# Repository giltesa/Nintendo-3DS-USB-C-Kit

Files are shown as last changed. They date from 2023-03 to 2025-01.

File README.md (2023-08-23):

# Nintendo 3DS USB-C Kit

The **Nintendo 3DS: USB-C Kit** is a board that allows to replace the original charging connector for a modern and standard **USB-C**.

**If your original connector is too old or damaged** and you need a new one, or **if you would like to charge your Nintendo 3DS with a standard USB-C charger**, like the charger of your **Nintendo Switch**, phone, laptop, you can with this kit.

This board is compatible with these four models:

*   Nintendo 3DS
*   Nintendo 3DS XL
*   Nintendo New 3DS
*   Nintendo New 3DS XL

The kit also includes a plastic piece which can holder the dock metal contacts from the original connector, that means you will be able to **charge it by USB-C** but also with the **charging dock**.

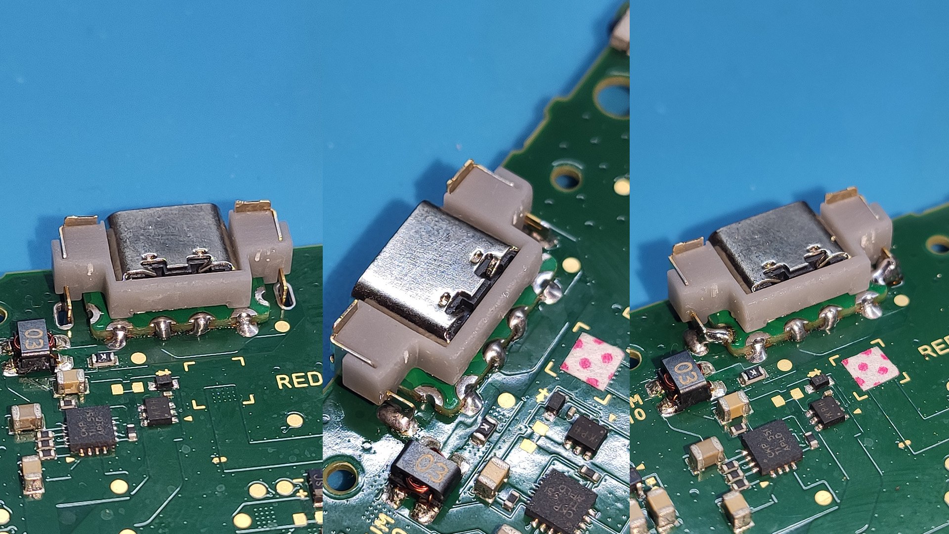
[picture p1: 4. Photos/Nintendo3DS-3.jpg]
Nintendo-3DS-USB-C-Kit

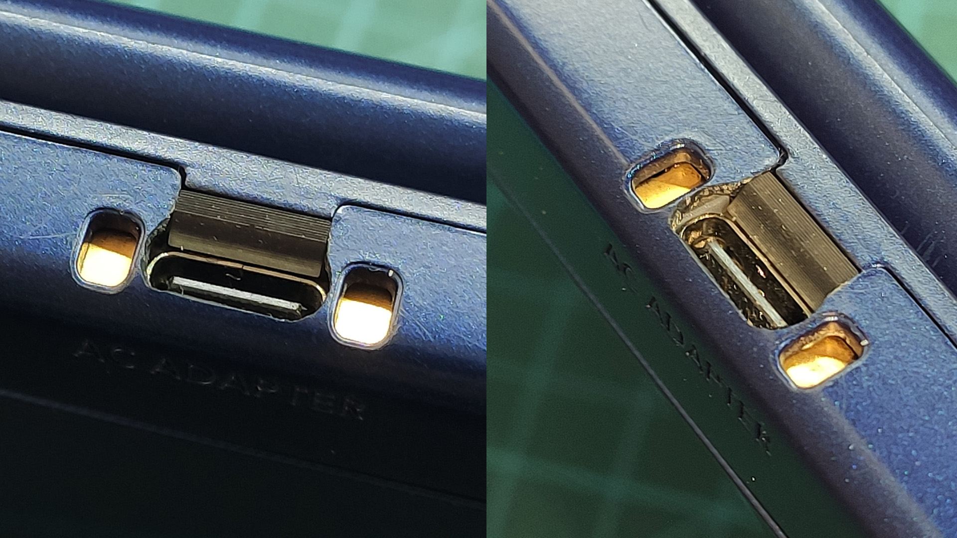
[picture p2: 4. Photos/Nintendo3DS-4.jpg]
Nintendo-3DS-USB-C-Kit


## Would you like it?

https://shop.giltesa.com/product/nintendo-3ds-usb-c-kit/

## More

- [giltesa.com](https://giltesa.com "giltesa.com")
- [twitter.com](https://twitter.com/giltesa "twitter.com")

## License

This project is licensed under a **Creative Commons** license:
**[Attribution-NonCommercial-ShareAlike 4.0 International (CC BY-NC-SA 4.0) ](https://creativecommons.org/licenses/by-nc-sa/4.0/)**

Check the [LICENSE.md](LICENSE.md) for more information.

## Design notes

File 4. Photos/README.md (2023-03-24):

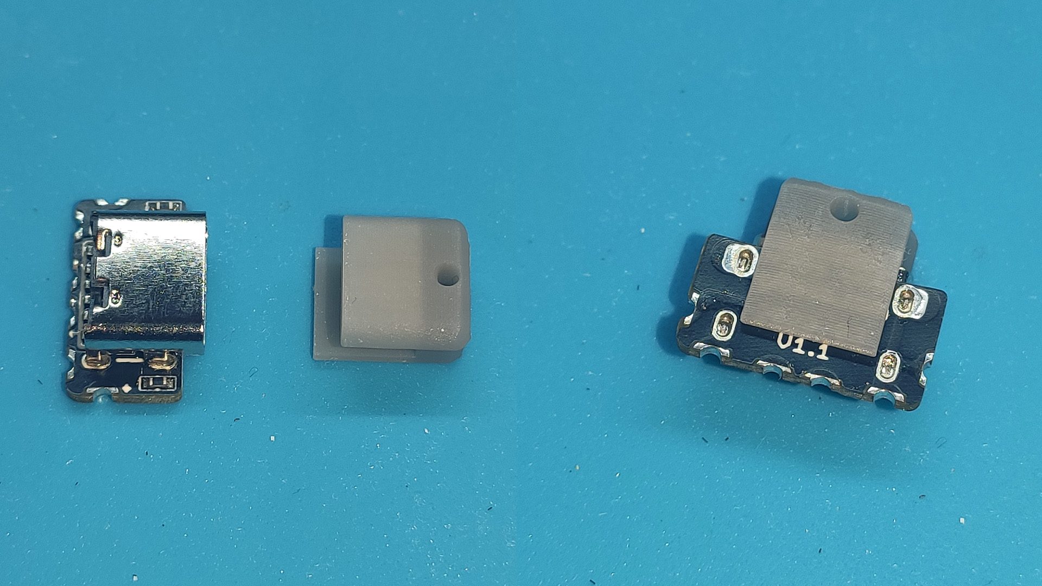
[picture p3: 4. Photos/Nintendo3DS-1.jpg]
Nintendo-3DS-USB-C-Kit

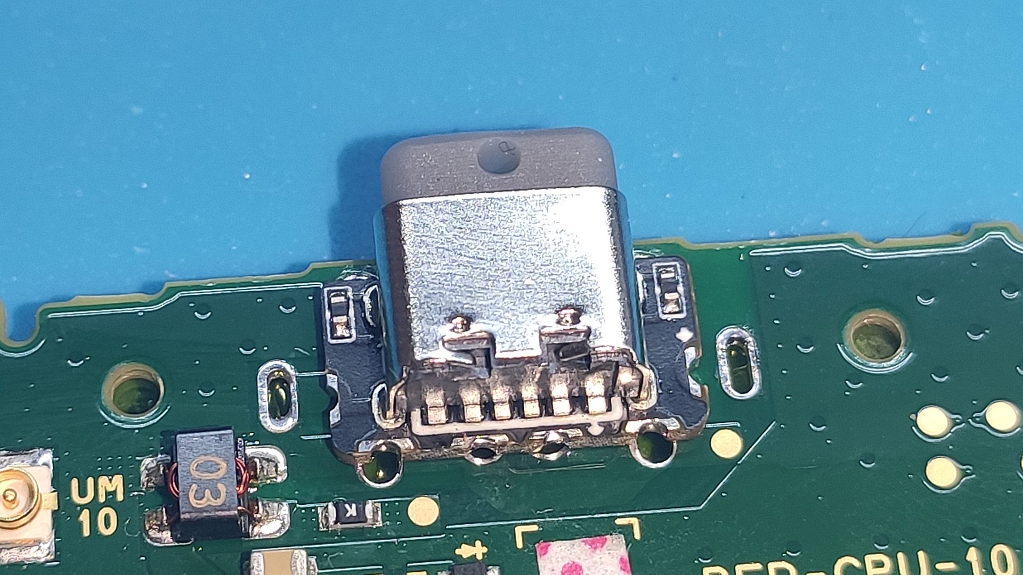
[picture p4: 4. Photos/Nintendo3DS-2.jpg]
Nintendo-3DS-USB-C-Kit

Nintendo-3DS-USB-C-Kit
Nintendo-3DS-USB-C-Kit
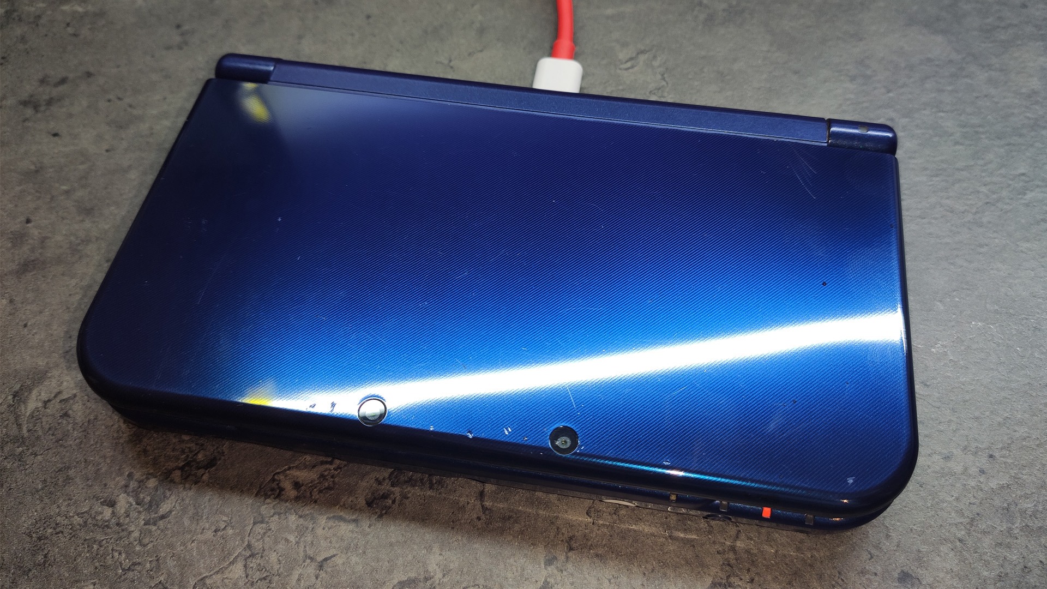
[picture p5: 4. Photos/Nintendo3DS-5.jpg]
Nintendo-3DS-USB-C-Kit


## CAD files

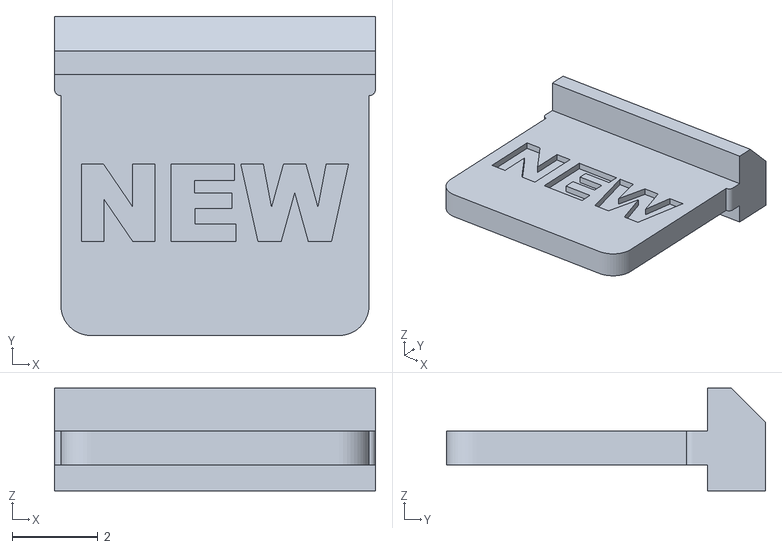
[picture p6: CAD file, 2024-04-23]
2. Renders, 3D models/Cap/Nintendo 3DS - Cap v31 NEW.stl
7.50 x 7.45 x 2.40

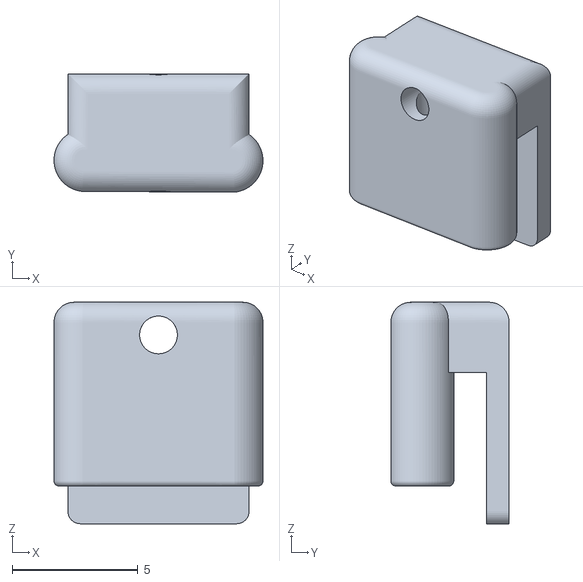
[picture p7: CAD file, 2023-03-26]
2. Renders, 3D models/Center tool/Nintendo 3DS - Center tool v1.1 v17.stl
8.30 x 4.70 x 8.80

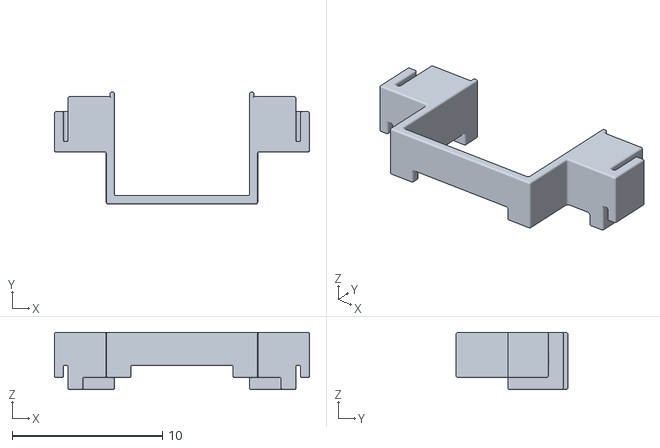
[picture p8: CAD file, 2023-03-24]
2. Renders, 3D models/Dock holder/Nintendo 3DS - Dock holder v1.1 v23.stl
17.0 x 7.45 x 3.80

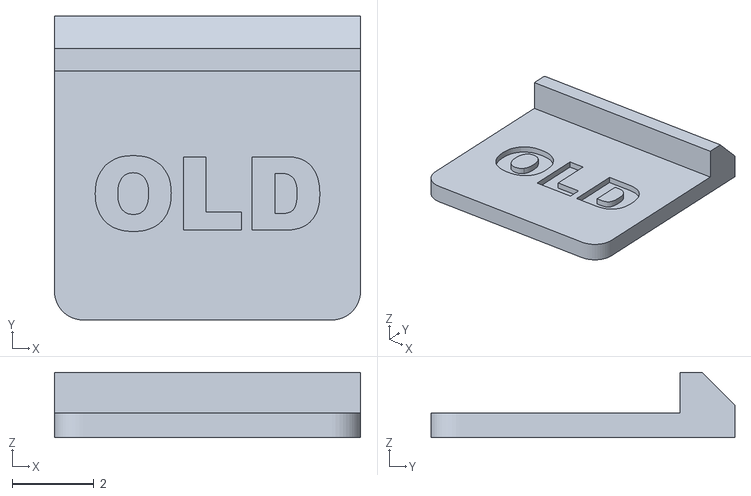
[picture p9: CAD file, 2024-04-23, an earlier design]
2. Renders, 3D models/Cap/Nintendo 3DS - Cap v8 OLD.stl
7.50 x 7.45 x 1.60

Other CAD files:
2. Renders, 3D models/Cap/Nintendo 3DS - Cap v31 NEW.f3d
2. Renders, 3D models/Cap/Nintendo 3DS - Cap v8 OLD.f3d
2. Renders, 3D models/Center tool/Nintendo 3DS - Center tool v1.1 v17.f3d
2. Renders, 3D models/Dock holder/Nintendo 3DS - Dock holder v1.1 v23.f3d
2. Renders, 3D models/Nintendo 3DS USB-C v1.0.skp
2. Renders, 3D models/Nintendo 3DS USB-C v1.1.skp

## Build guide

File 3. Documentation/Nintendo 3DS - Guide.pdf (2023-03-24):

# USB-C KIT For

# Nintendo 3DS 3DS XL New 3DS New 3DS XL

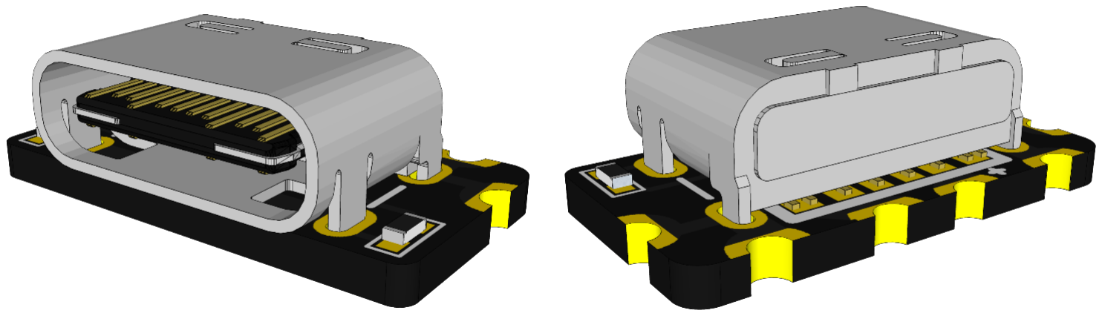
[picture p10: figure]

### Nintendo 3DS USB-C Kit

HTTPS://SHOP.GILTESA.COM/PRODUCT/NINTENDO-3DS-USB-C-KIT

# PLEASE READ THROUGH THESE INSTRUCTIONS

ENTIRELY BEFORE ATTEMPTING TO INSTALL.

# WARNING: IF YOU ARE NOT COMFORTABLE WITH SOLDERING, OR PERFORMING ANY STEP IN THIS

GUIDE, DO NOT PERFORM THE INSTALL YOURSELF.

# FIND SOMEONE WHO IS COMFORTABLE TO DO IT FOR

YOU.

# Description

The Nintendo 3DS: USB-C Kit is a board that allows to replace the original charging connector for a modern and standard USB-C.

If your original connector is too old or damaged and you need a new one, or if you would like to charge your Nintendo 3DS with a standard USB-C charger, like the charger of your Nintendo Switch, phone, laptop, you can with this kit.

This board is compatible with these four models:

- Nintendo 3DS
- Nintendo 3DS XL
- Nintendo New 3DS
- Nintendo New 3DS XL

The kit also includes a plastic piece which can holder the dock metal contacts from the original connector, that means you will be able to charge it by USB-C but also with the charging dock.

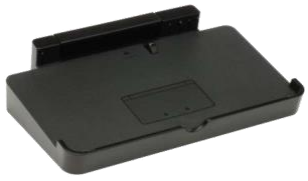
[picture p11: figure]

# FEATURES

- Plastic holder made by resin 3D printer for charging dock compatibility.
- Charging your Nintendo with:
- USB power banks
- USB-A chargers
- USB-C chargers
- USB-C PD chargers (normal speed, not fast)
- USB-A to USB-C cables
- USB-C to USB-C cables

# INCLUDED

- 1 board.
- 3 plastic parts:
- Tool to centre the board during the installation.
- Pads holder for dock charging.
- Cap to cover the hole.

# Recommended / REQUIRED (NOT INCLUDED)

- Dock metal contacts, from the original connector (optional)
- Phillips screwdriver
- Scissors
- File tool set
- Kapton tape
- Soldering iron
- Tin
- Flux
- Desoldering pump
- Desoldering mesh
- Isopropyl alcohol
- Instant glue (Loctite, Super Glue)

# Board details

This tiny board has eight pads in about 1cm²
surface, which means it requires high soldering skills. The following explains what each pad is for.

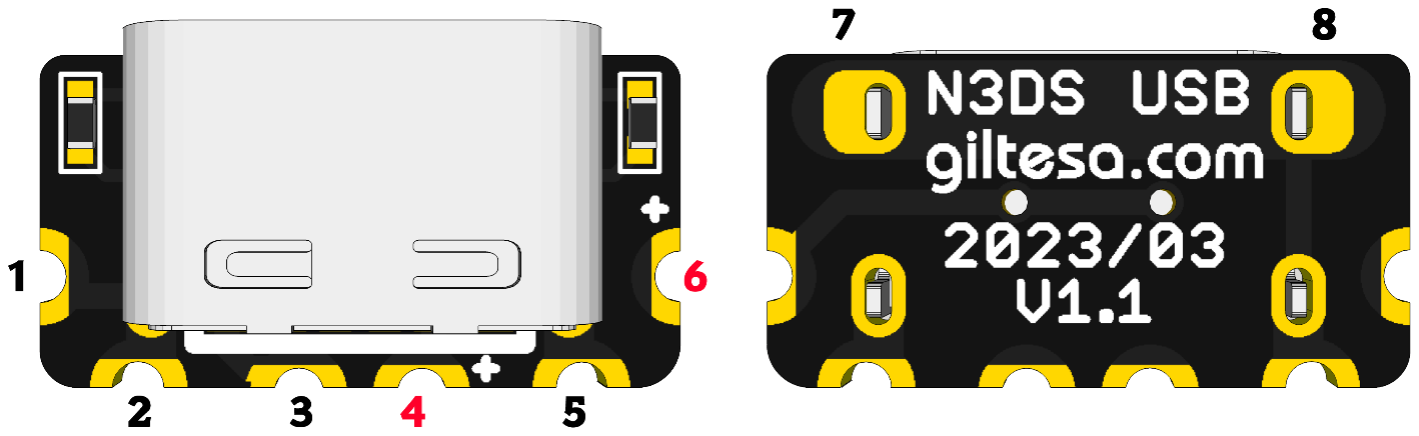
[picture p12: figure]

Starting from the left to the right:

1. GND: | The ground pad.
2. GND: | The ground pad.
3. GND: | The ground pad.
4. VCC: | The 5V line from the USB-C.
5. GND: | The ground pad.
6. VCC: | The 5V line from the USB-C.
7. GND: | The ground pad.
8. GND: | The ground pad.

# INSTALLATION STEPS

Please, carefully read the following steps for a successful installation.

## Pre installation Steps

Before the installation, your Nintendo 3DS may need some extra steps to have it ready for the kit.

1. Disassembly the Nintendo 3DS

Nintendo 3DS use the phillips screws to close the shell. First remove the two-screw silicon covers and the two screws which hold the 3DS plastic back cover.

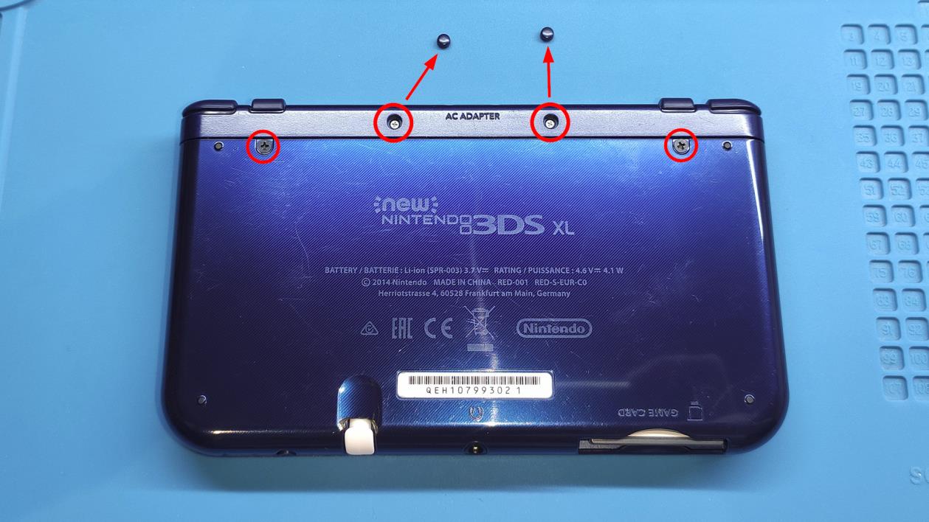
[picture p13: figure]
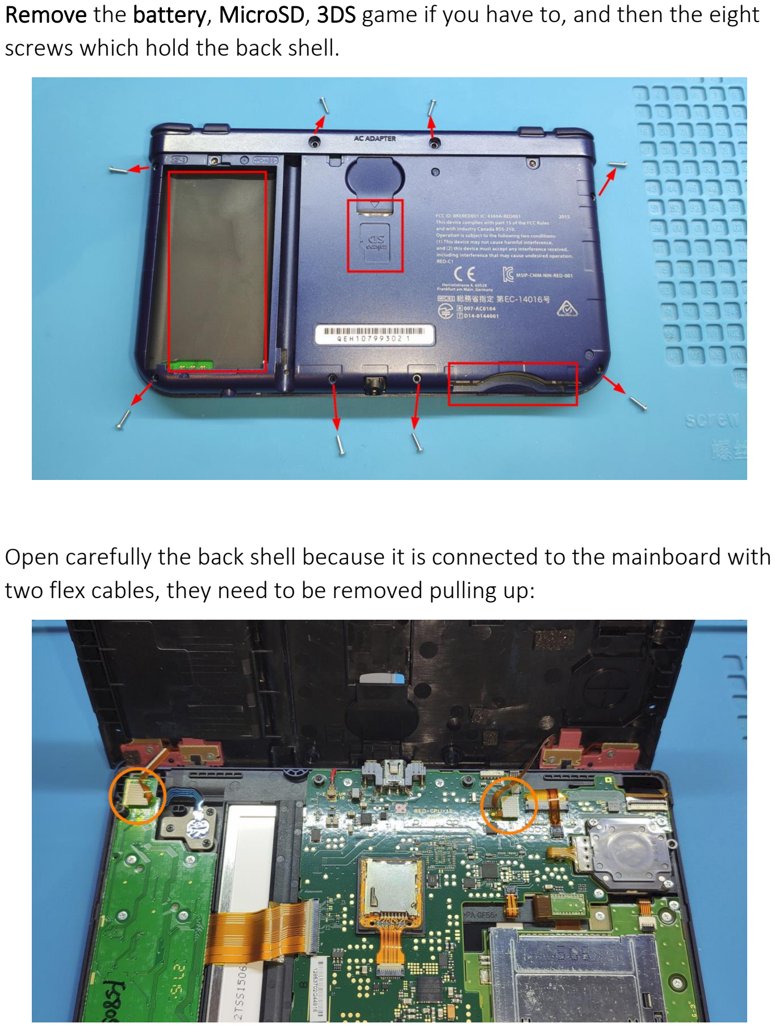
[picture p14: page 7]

Remove the battery, MicroSD, 3DS game if you have to, and then the eight screws which hold the back shell.

Open carefully the back shell because it is connected to the mainboard with two flex cables, they need to be removed pulling up:

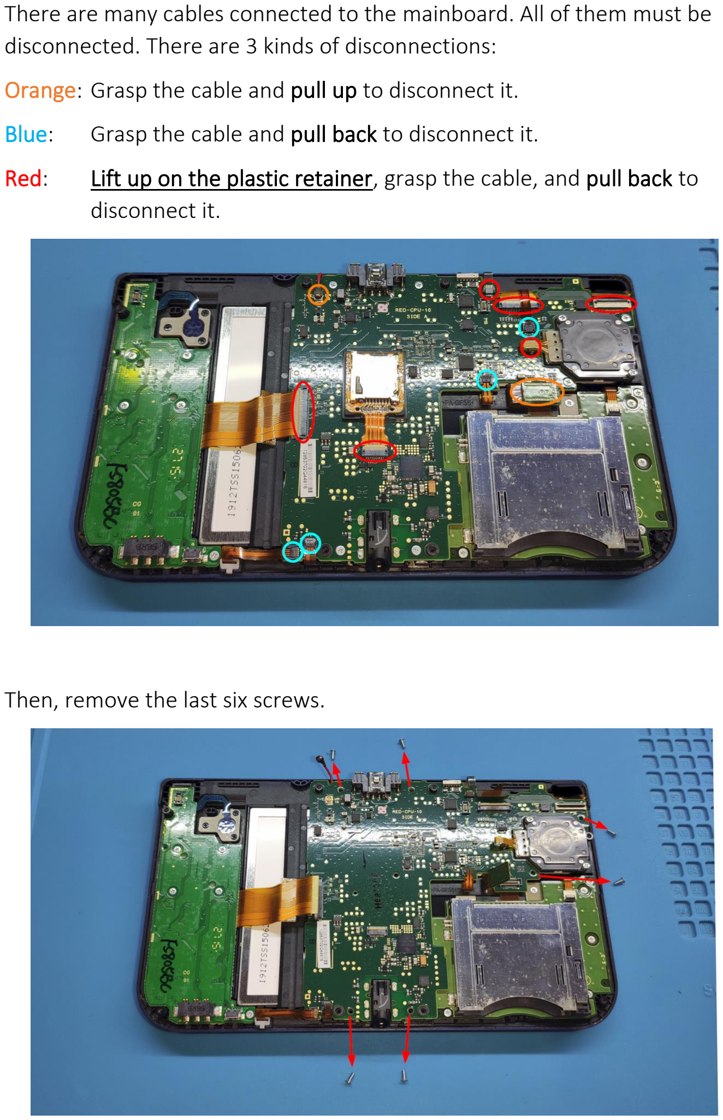
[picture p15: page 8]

There are many cables connected to the mainboard. All of them must be disconnected. There are 3 kinds of disconnections:

Orange: Grasp the cable and pull up to disconnect it.

Blue: | Grasp the cable and pull back to disconnect it.
Red: | Lift up on the plastic retainer, grasp the cable, and pull back to disconnect it.

Then, remove the last six screws.

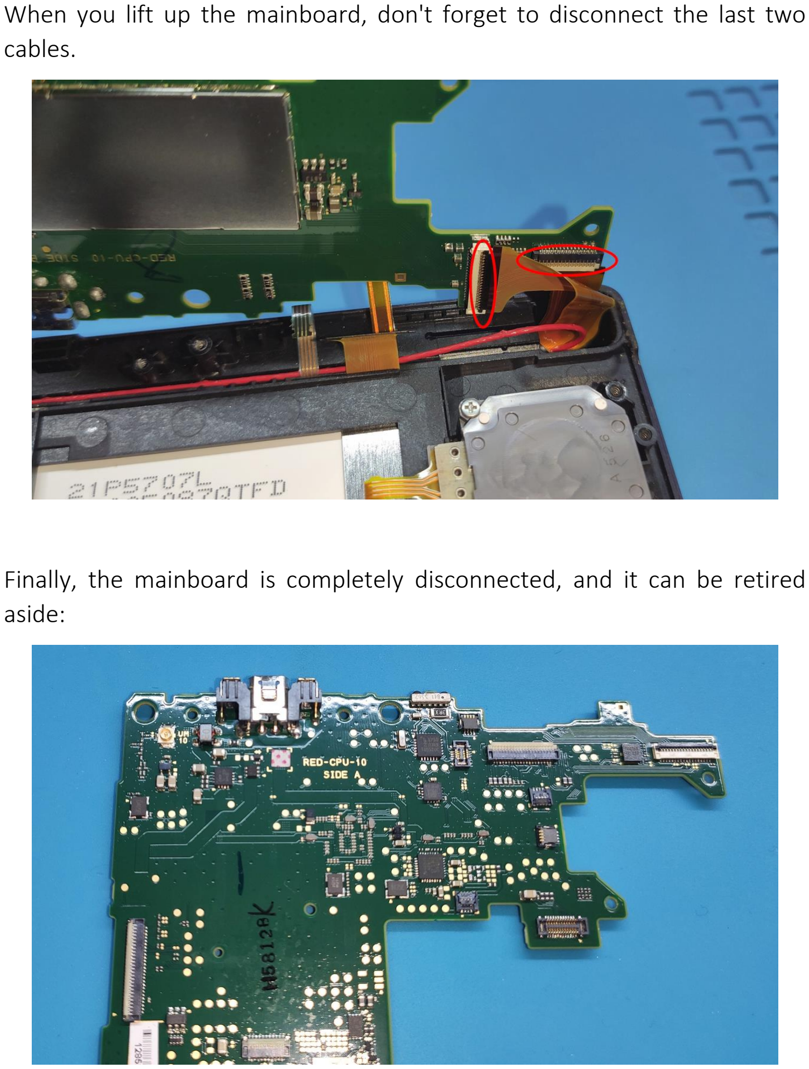
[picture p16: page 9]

When you lift up the mainboard, don't forget to disconnect the last two cables.

Finally, the mainboard is completely disconnected, and it can be retired aside:

## installation Steps

1. Protect the nearest components

Use Kapton tape to protect and avoid any damage to the electronic components that are next to the connector.

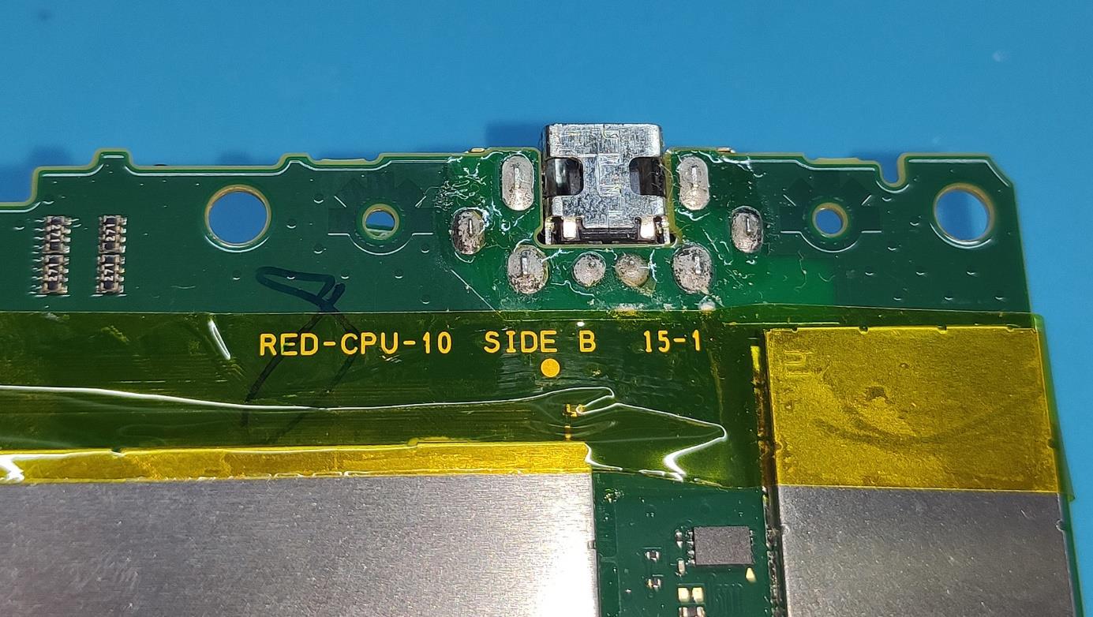
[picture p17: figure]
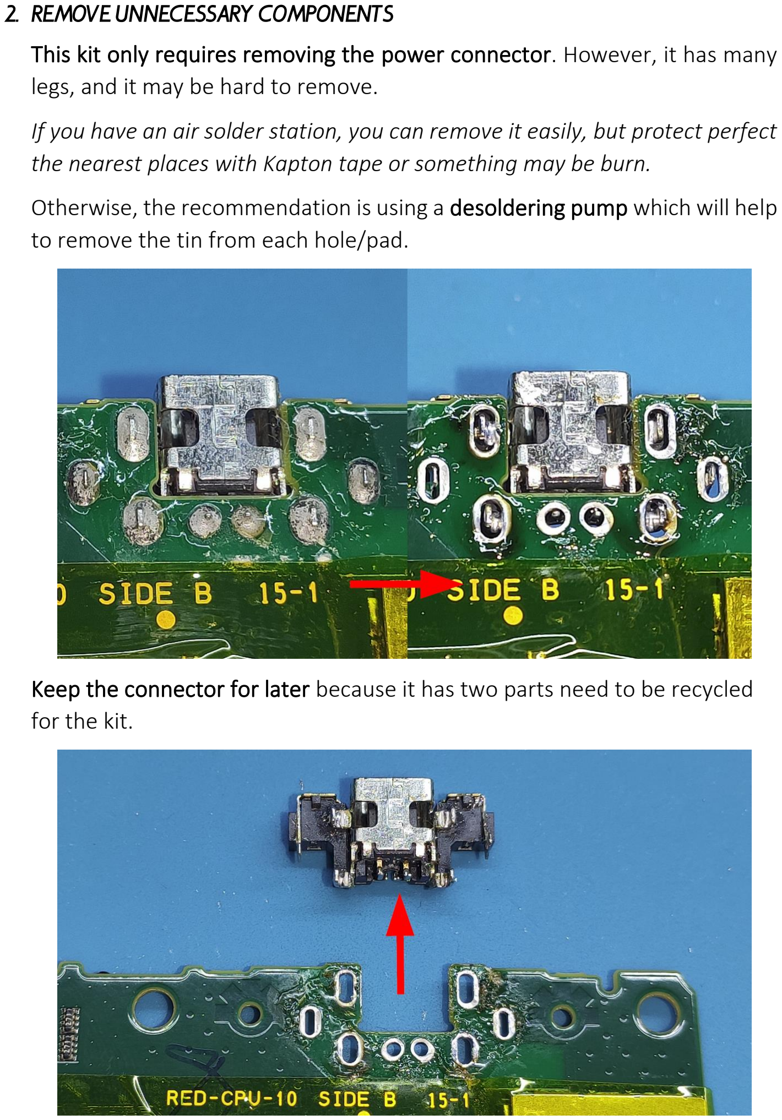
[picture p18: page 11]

2. Remove unnecessary components

This kit only requires removing the power connector. However, it has many legs, and it may be hard to remove.

If you have an air solder station, you can remove it easily, but protect perfect the nearest places with Kapton tape or something may be burn.

Otherwise, the recommendation is using a desoldering pump which will help to remove the tin from each hole/pad.

Keep the connector for later because it has two parts need to be recycled for the kit.

3. Clean the board

After the component is removed, it may be dirty, clean both sides.

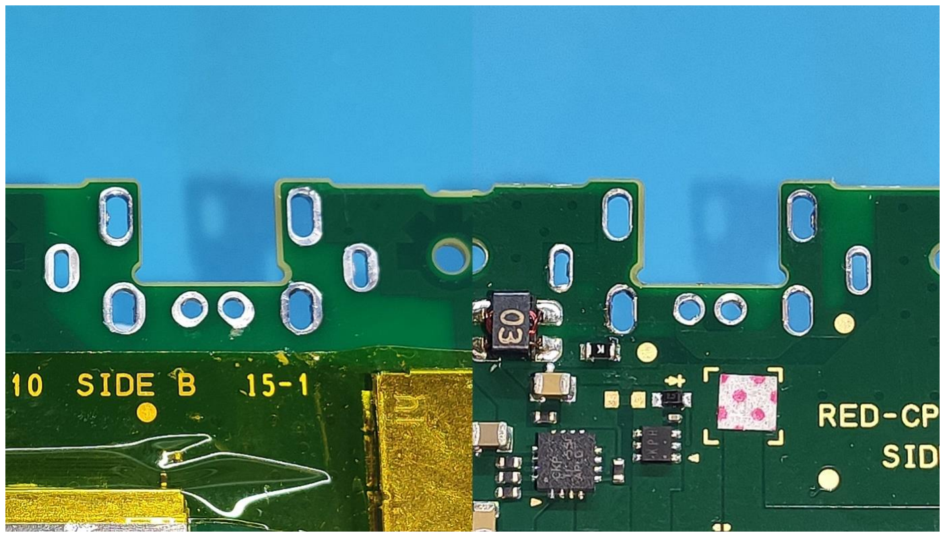
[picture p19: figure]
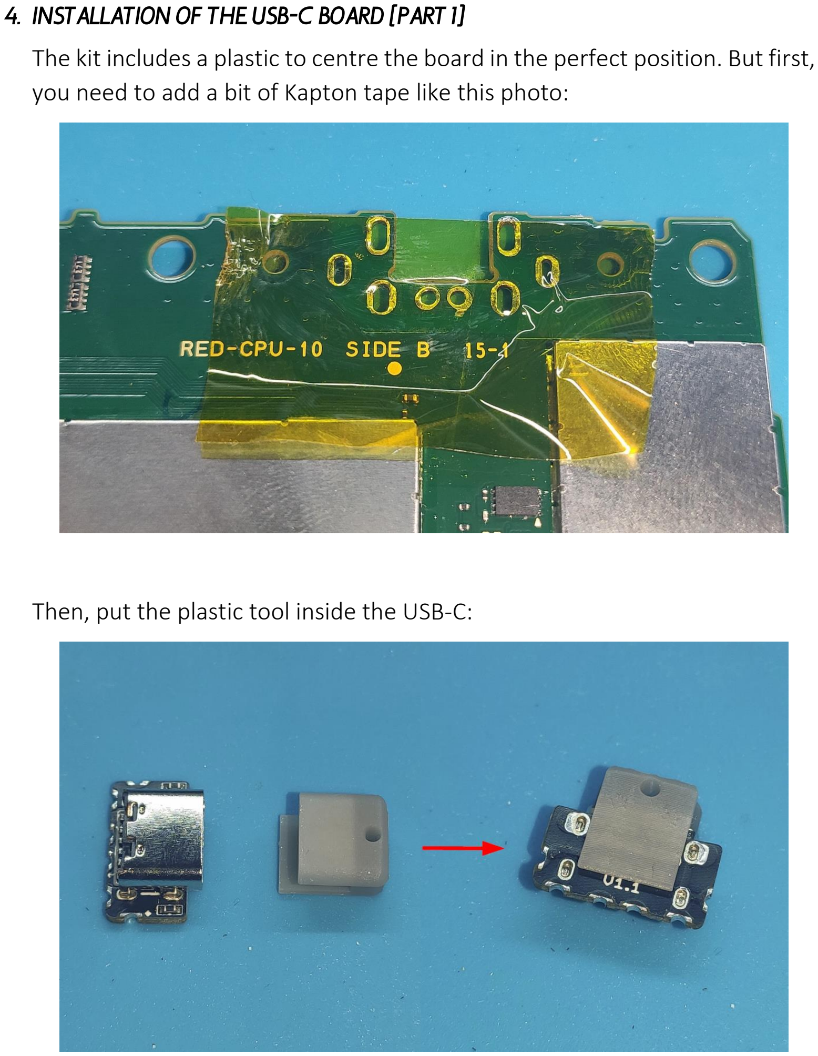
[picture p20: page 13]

4. Installation of the USB-C board (part 1)

The kit includes a plastic to centre the board in the perfect position. But first, you need to add a bit of Kapton tape like this photo:

Then, put the plastic tool inside the USB-C:

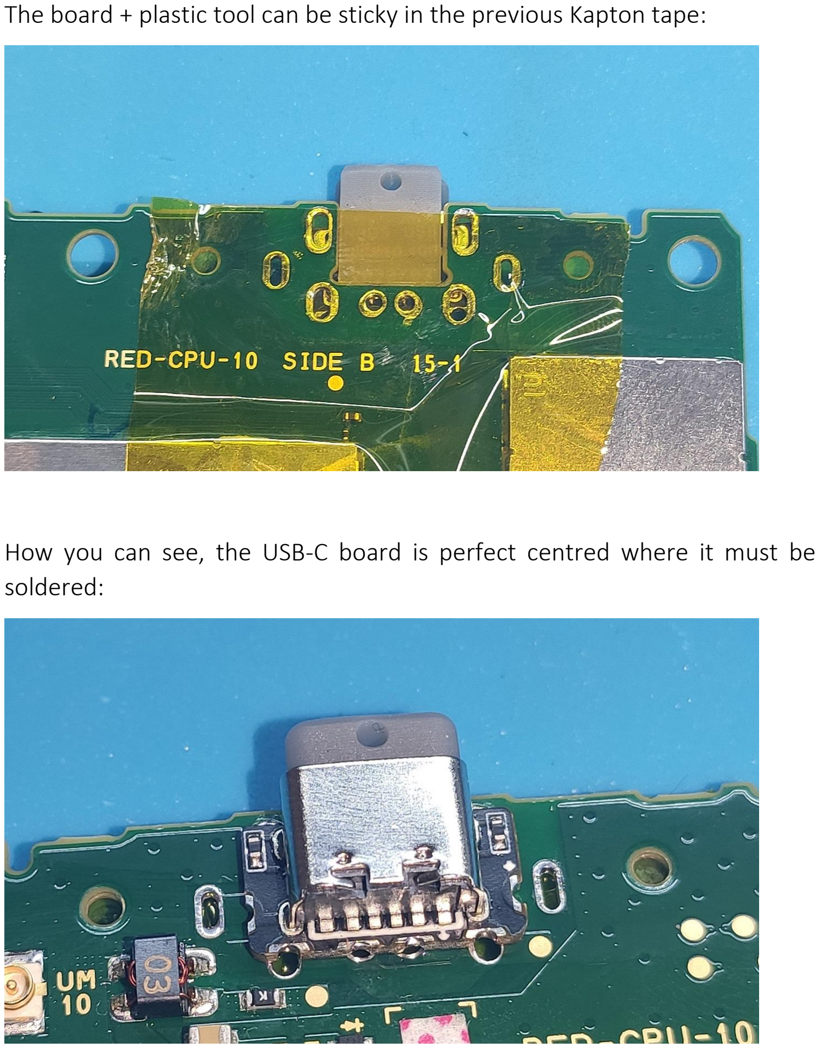
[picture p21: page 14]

The board + plastic tool can be sticky in the previous Kapton tape:

How you can see, the USB-C board is perfect centred where it must be soldered:

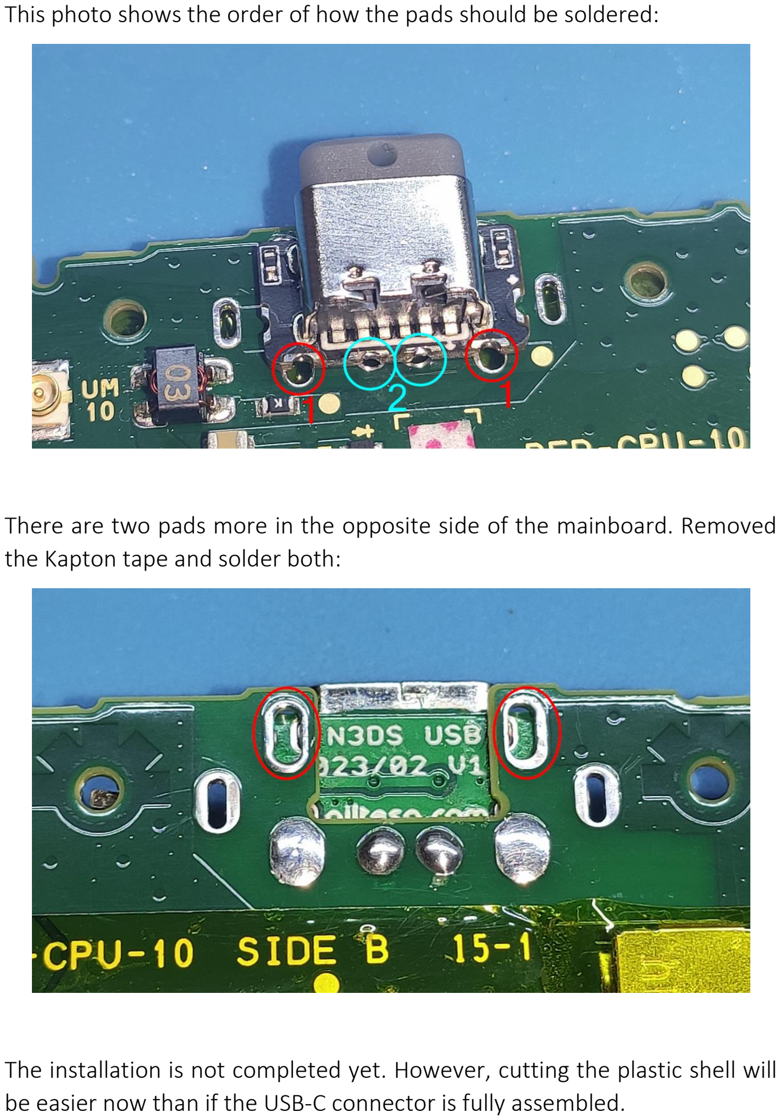
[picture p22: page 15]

This photo shows the order of how the pads should be soldered:

There are two pads more in the opposite side of the mainboard. Removed the Kapton tape and solder both:

The installation is not completed yet. However, cutting the plastic shell will be easier now than if the USB-C connector is fully assembled.

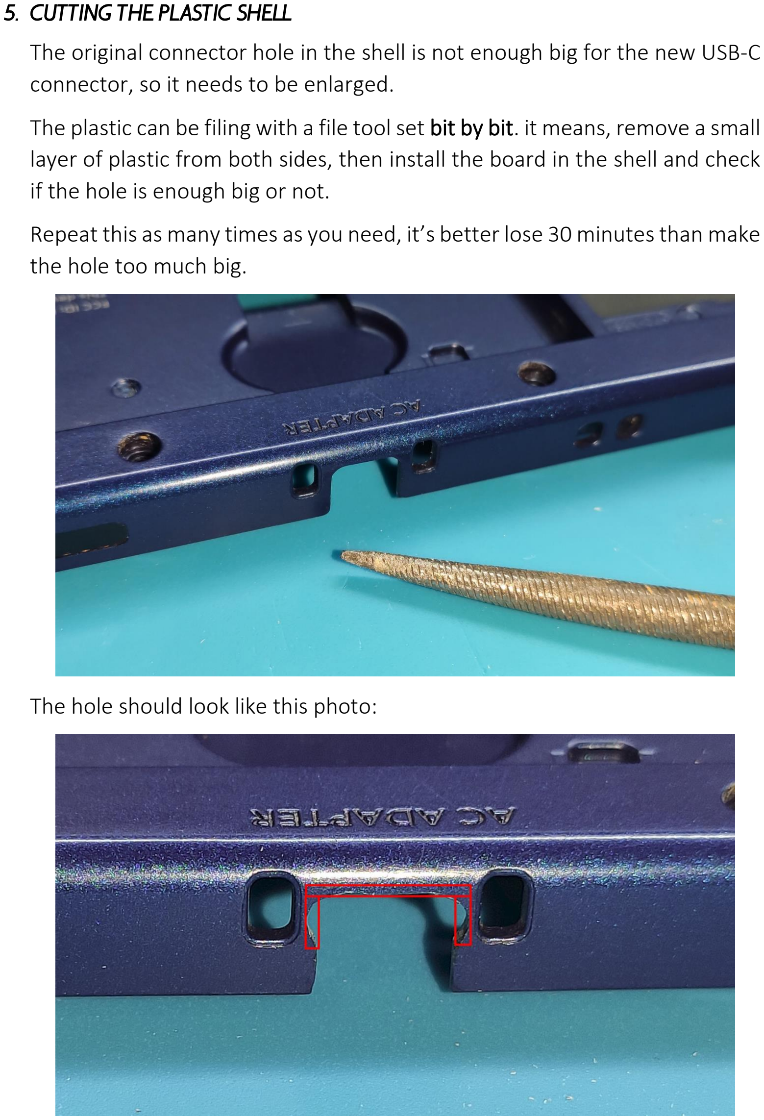
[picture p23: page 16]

5. Cutting the plastic shell

The original connector hole in the shell is not enough big for the new USB-C connector, so it needs to be enlarged.

The plastic can be filing with a file tool set bit by bit. it means, remove a small layer of plastic from both sides, then install the board in the shell and check if the hole is enough big or not.

Repeat this as many times as you need, it’s better lose 30 minutesthan make the hole too much big.

The hole should look like this photo:

Another photo from another angle:

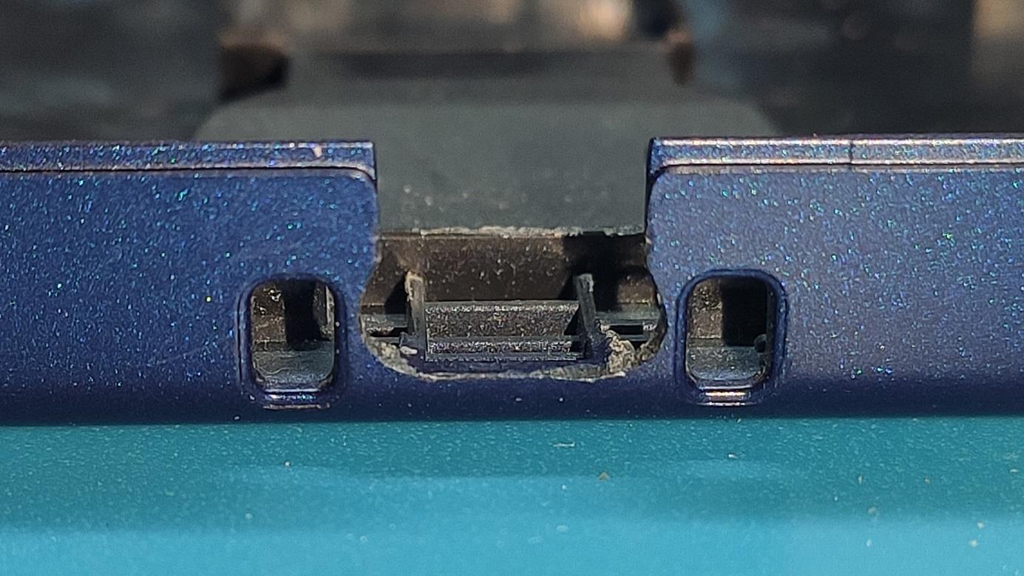
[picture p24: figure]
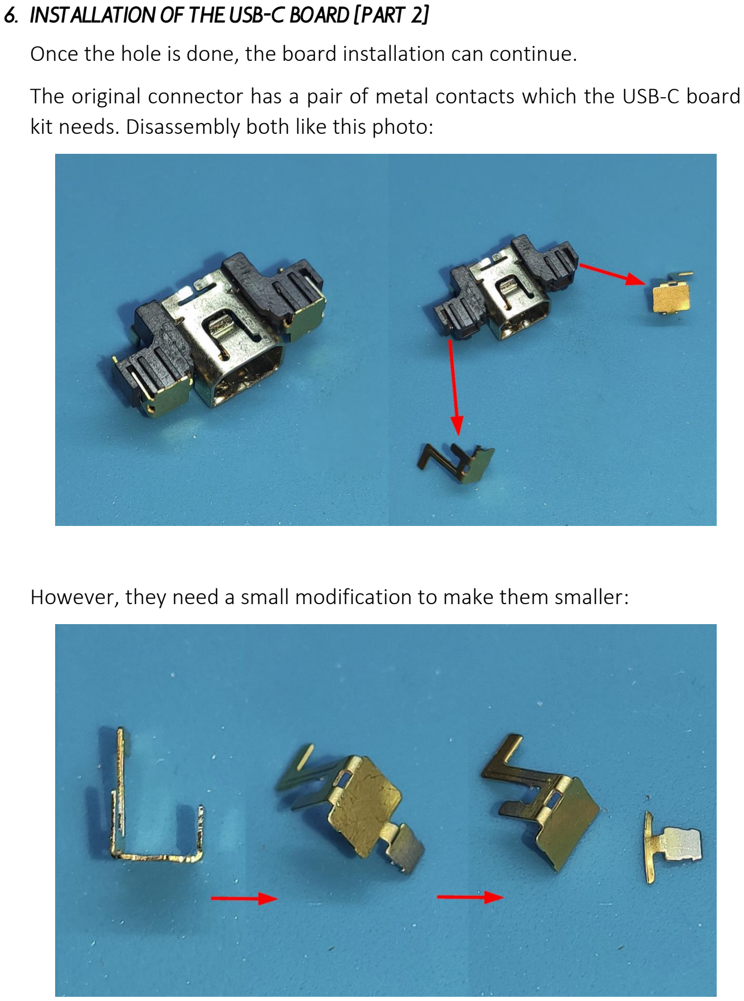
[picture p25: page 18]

6. Installation of the USB-C board (part 2)

Once the hole is done, the board installation can continue.

The original connector has a pair of metal contacts which the USB-C board kit needs. Disassembly both like this photo:

However, they need a small modification to make them smaller:

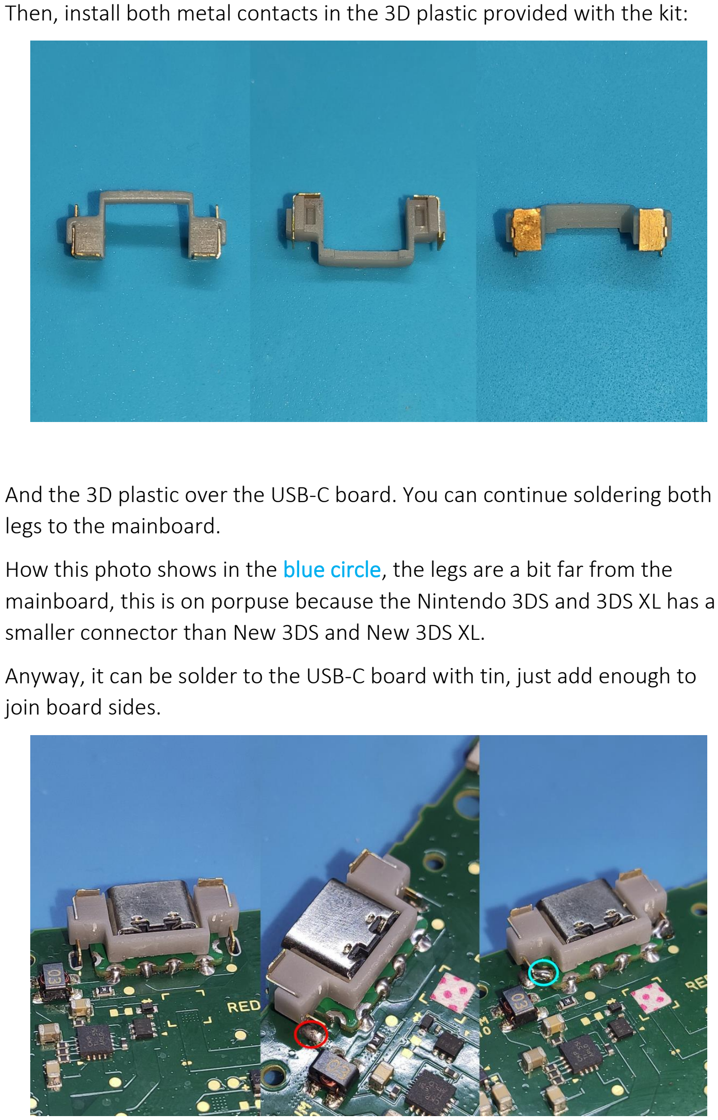
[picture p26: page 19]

Then, install both metal contacts in the 3D plastic provided with the kit:

And the 3D plastic over the USB-C board. You can continue soldering both legs to the mainboard.

How this photo shows in the blue circle, the legs are a bit far from the mainboard, this is on porpuse because the Nintendo 3DS and 3DS XL has a smaller connector than New 3DS and New 3DS XL.

Anyway, it can be solder to the USB-C board with tin, just add enough to join board sides.

Don’t forget as last step to install the plastic cap/cover. It will cover the part of the original charging connector, making the installation perfect.

This plastic has some letters which must be face to the USB-C board.

You can use strong tape over the plastic and the mainboard to hold it or use a drop of instant glue between the USB-C board and the plastic cap/cover.

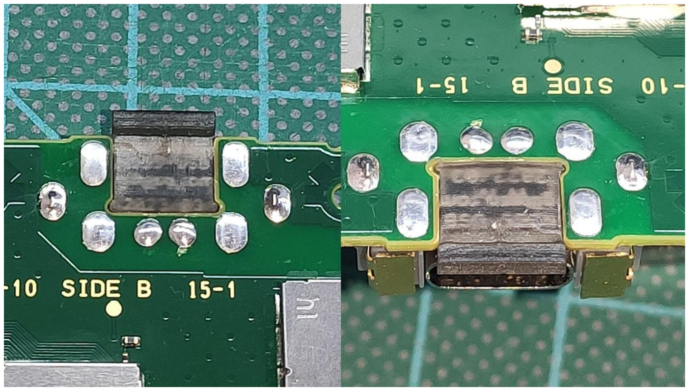
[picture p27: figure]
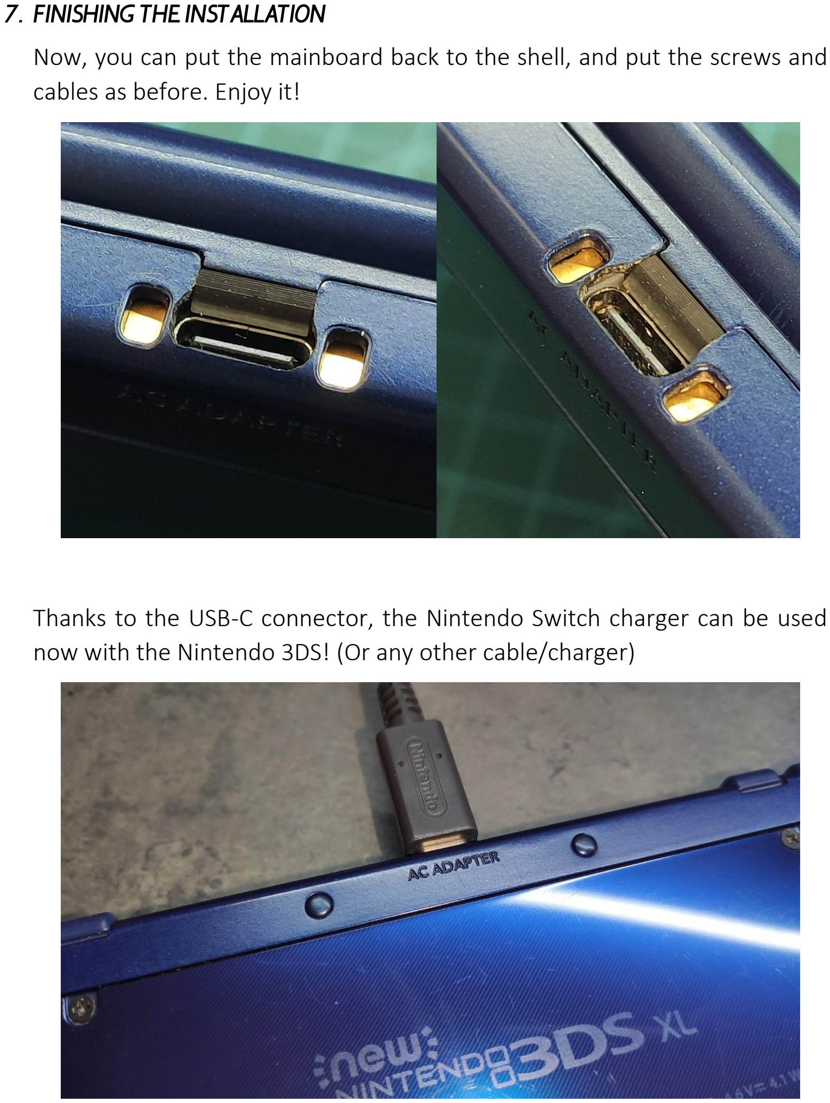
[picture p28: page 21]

7. Finishing the installation

Now, you can put the mainboard back to the shell, and put the screws and cables as before. Enjoy it!

Thanks to the USB-C connector, the Nintendo Switch charger can be used now with the Nintendo 3DS! (Or any other cable/charger)

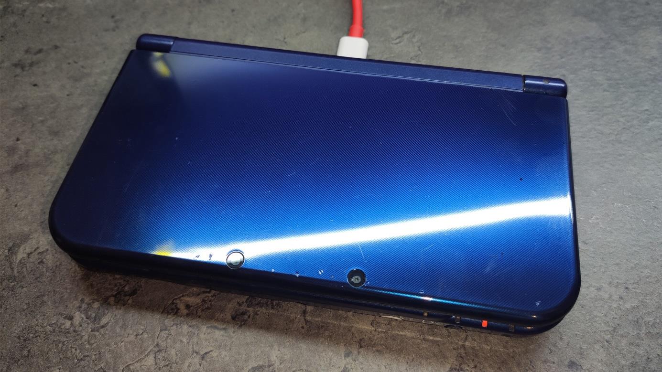
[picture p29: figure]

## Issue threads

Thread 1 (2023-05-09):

Could the gerbers and .skp files for this kit be released?

Jinraider, 2023-05-09:
Hey there,

I'm wondering if you could release the gerbers and .skp files for this PCB like you have for your other usb c projects?

giltesa, 2023-05-09:
Hello Jinraider,
I just did it now. But I think something is happening with GitHub that doesn't update the page. If you clone/downlad the repo the changes are there. I think it's only the website that is broken.

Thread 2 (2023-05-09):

Could the gerbers and .skp files for this kit be released?

Jinraider, 2023-05-09:
Hey there,

I'm wondering if you could release the gerbers and .skp files for this PCB like you have for your other usb c projects?

giltesa, 2023-05-09:
Hello Jinraider,
I just did it now. But I think something is happening with github that
doesn't update the page. If you clone the repo the changes are there. I
think it's only the website that is broken.

Kind regards,
giltesa

El mar, 9 may 2023 a las 13:38, Jinraider ***@***.***>)
escribió:

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

Closed 2023-05-09.

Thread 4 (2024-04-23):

What thickness is the PCB?

chunkysteveo, 2024-04-23:
Hi - great project!

What's the PCB thickness for this?

Steve

giltesa, 2024-04-23:
Hello Steve,
The PCB thickness is 1.0mm
Kind regards,
giltesa

chunkysteveo, 2024-04-23:
Thanks for the info - much appreciated!

Closed 2024-04-23.

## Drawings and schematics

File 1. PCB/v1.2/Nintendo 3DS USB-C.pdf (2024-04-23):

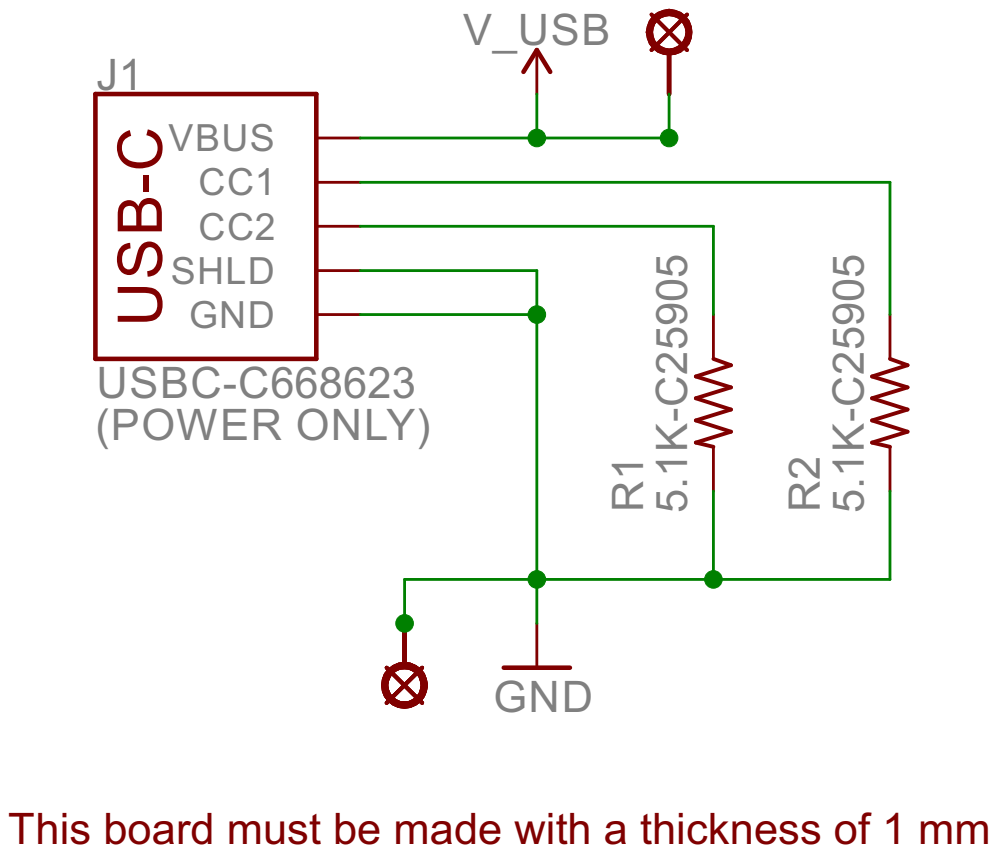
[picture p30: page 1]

This board must be made with a thickness of 1 mm

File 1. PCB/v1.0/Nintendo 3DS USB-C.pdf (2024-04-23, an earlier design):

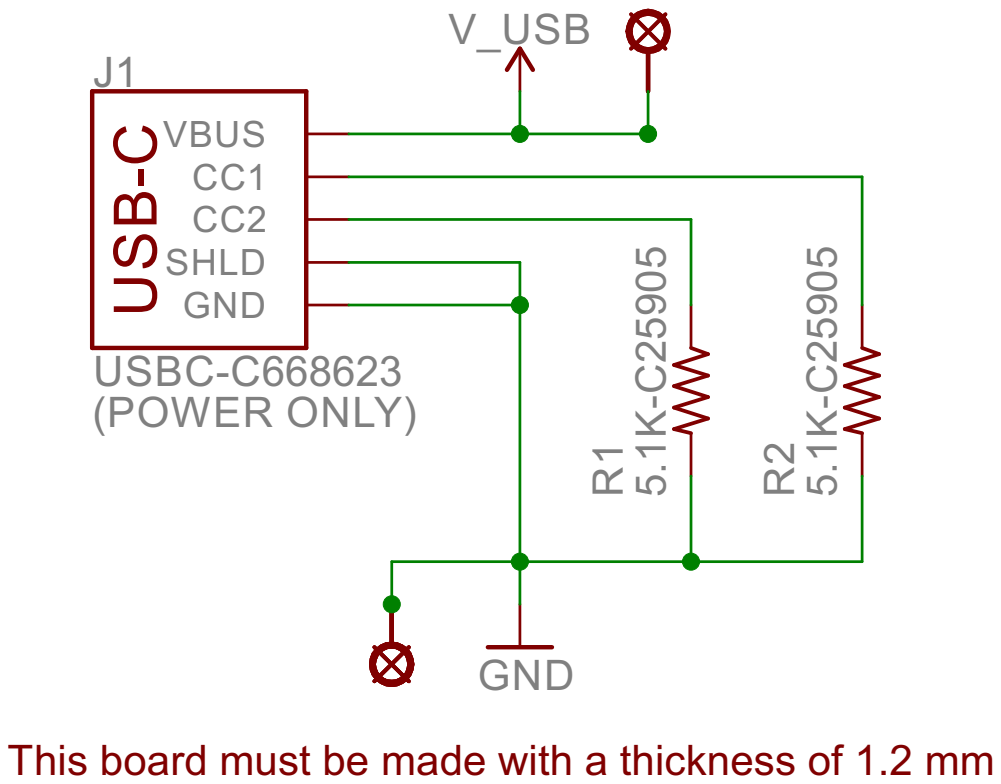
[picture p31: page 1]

This board must be made with a thickness of 1.2 mm

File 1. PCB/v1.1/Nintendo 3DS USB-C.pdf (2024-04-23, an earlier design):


This board must be made with a thickness of 1 mm

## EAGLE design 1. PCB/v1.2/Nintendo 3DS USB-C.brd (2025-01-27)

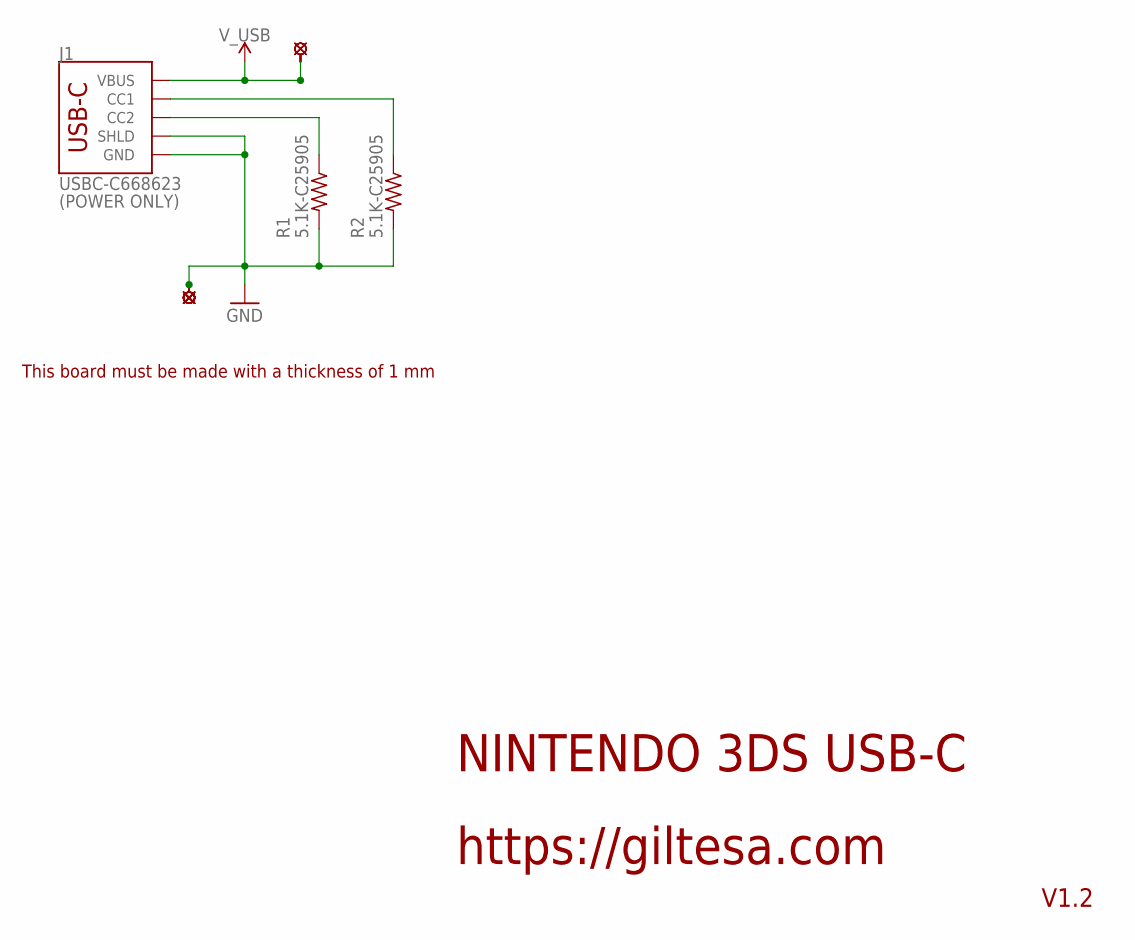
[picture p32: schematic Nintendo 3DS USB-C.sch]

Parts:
J1: USBC-C668623; USB-C_6P
R1, R2: 5.1K-C25905; R0402
U$2, U$3, U$4, U$6, U$7, U$8: PAD_1.0H; PAD_1.0_HALF_MASK

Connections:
GND: J1.A12-GND (GND), J1.B12-GND (GND), J1.SHLD1 (SHLD), J1.SHLD2 (SHLD), J1.SHLD3 (SHLD), J1.SHLD4 (SHLD), R1.2, R2.2, U$4.P$1, U$6.P$1, U$7.P$1, U$8.P$1
unnamed: J1.B5 (CC2), R1.1
unnamed: J1.A5 (CC1), R2.1
V_USB: J1.A9-VBUS (VBUS), J1.B9-VBUS (VBUS), U$2.P$1, U$3.P$1

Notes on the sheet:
NINTENDO 3DS USB-C
https://giltesa.com
V1.2
This board must be made with a thickness of 1 mm
(POWER ONLY)

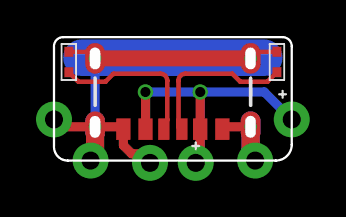
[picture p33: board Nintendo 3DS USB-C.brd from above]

Board: 2 copper layers, 13.2 x 6.9 mm, 10 parts (1 on the bottom side), 4 nets.

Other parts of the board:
U$11: GILTESA.COM_MASK_7MM

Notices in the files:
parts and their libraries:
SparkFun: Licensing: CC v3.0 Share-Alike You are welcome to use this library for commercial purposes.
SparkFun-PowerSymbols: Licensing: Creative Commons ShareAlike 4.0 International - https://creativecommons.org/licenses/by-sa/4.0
